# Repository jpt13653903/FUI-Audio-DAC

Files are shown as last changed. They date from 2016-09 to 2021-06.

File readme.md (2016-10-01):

### USB Vendor ID and Product ID

At present, the project uses the Test ID (1209 | 0001) provided by [PID Codes](http://pid.codes/1209/0001).  It is not unique and may therefore not be used outside test environments.

### More Information

For more information, see the [project Wiki](https://sourceforge.net/p/fui-audio-dac/wiki/)

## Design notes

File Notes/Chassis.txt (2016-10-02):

Large Aluminium Enclosure:
http://www.communica.co.za/Catalog/Details/P1733724242

Small Plastic Enclosure:
http://www.mantech.co.za/ProductInfo.aspx?Item=55M0019

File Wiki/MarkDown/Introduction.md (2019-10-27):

[[include repo=source path=Wiki/MarkDown/Header.md]]

[TOC]

# Introduction

## 1. Overview

The FUI Audio DAC is an open-hardware and -firmware project that implements a USB-input fully-digital class-D audio amplifier.  A Microchip PIC-based remote control is also included.

The generic Windows USB&nbsp;audio driver is used to stream 48&nbsp;kSps&nbsp;stereo audio to the amplifier.  The generic Windows&nbsp;HID driver is used to interface a volume control knob and various buttons to the computer.  These buttons are implemented on a remote control, which is implemented by means of an [off-the-shelf 433&nbsp;MHz ASK module](http://www.communica.co.za/Catalog/Details/P1929638763) (FS1000A and C218D001C pair).  Intended functions include *volume up*, *volume down*, *play/pause*, *next track*, *previous track* and *stop* controls.

Volume control is implemented as a combination of bus voltage control and audio stream gain control.

The block diagram below provides a system overview.  The FPGA used for this project is an [Altera Max 10](https://www.altera.com/products/fpga/max-series/max-10/overview.html), which is on a [BeMicro Max 10](https://www.arrow.com/en/products/bemicromax10/arrow-development-tools) development kit.  The microprocessor used for the remote control is a [Microchip PIC16F676](http://www.microchip.com/wwwproducts/en/PIC16F676).

<center markdown>System Block Diagram</center>

## 2. Firmware

All processing is done on FPGA, including the USB-physical, USB-SIE, HID interface, clock-recovery, bus voltage regulation, noise-shaping and PWM output.  An overview of the firmware is provided in the block diagram below.

<center markdown>Firmware Block Diagram</center>

## 3. USB Vendor ID and Product ID

At present, the project uses the Test ID provided by [PID Codes](http://pid.codes/1209/0001).  It is not unique and may therefore not be used outside test environments.

## 4. Development Software

The project is developed using:

- [TinyCAD](https://sourceforge.net/projects/tinycad/)
- [FreePCB](http://freepcb.com/) (or you can use [the fork](https://bitbucket.org/mplough/freepcb/wiki/Home))
- [MPLAB-X](http://www.microchip.com/mplab/mplab-x-ide), which comes with a free version of the [XC&nbsp;compiler](http://www.microchip.com/mplab/compilers)
- [Quartus Prime Lite](https://www.altera.com/products/design-software/fpga-design/quartus-prime/overview.html)
- [InkScape](https://inkscape.org/)

The source is available from the [git repository](https://sourceforge.net/p/fui-audio-dac/source/) and [GitHub](https://github.com/jpt13653903/FUI-Audio-DAC).

[[include repo=source path=Wiki/MarkDown/Footer.md]]

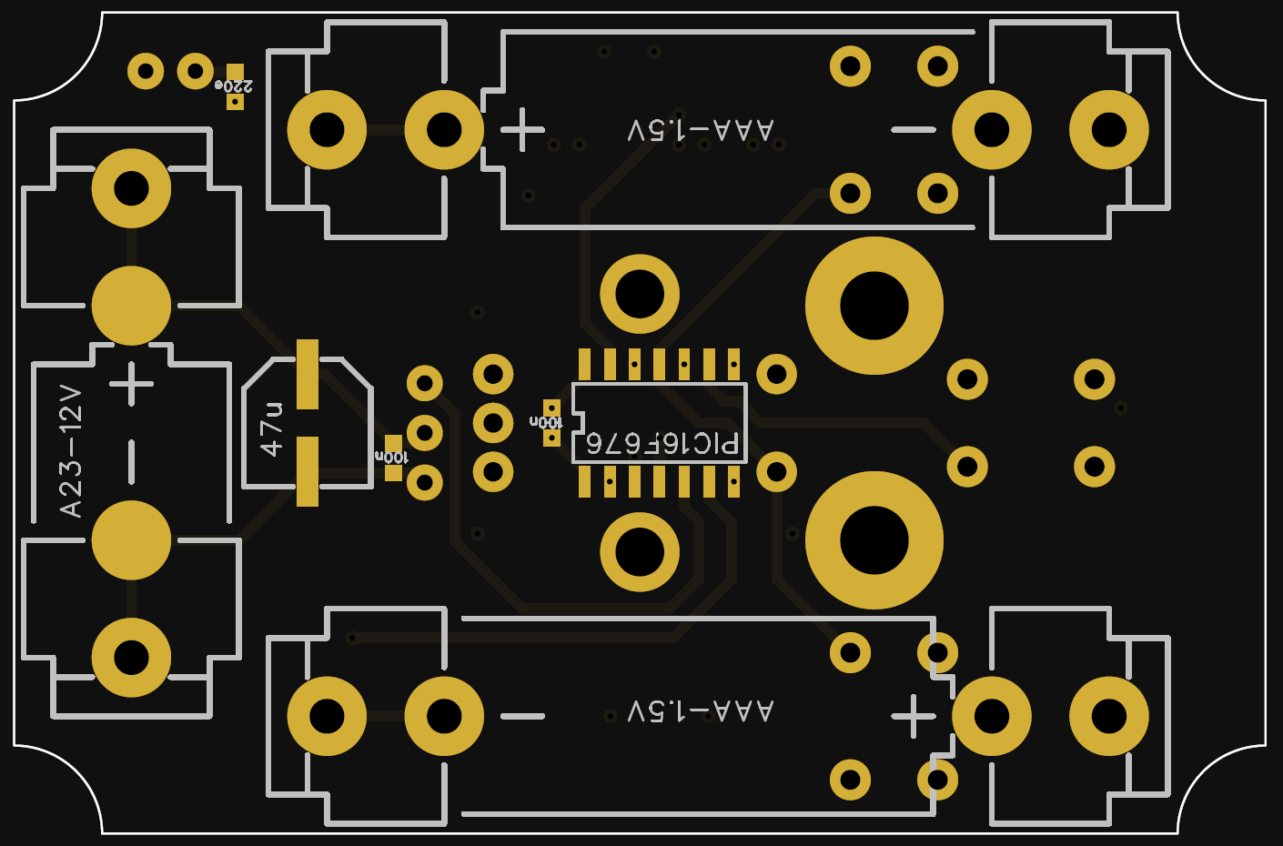
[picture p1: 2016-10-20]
SketchUp/Textures/Remote PCB Bottom.png

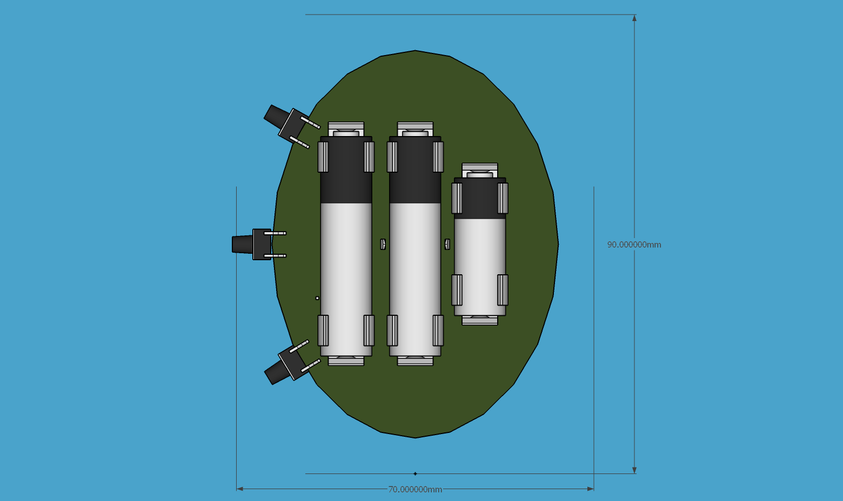
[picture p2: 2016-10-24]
SketchUp/Remote - Side Buttons - Bottom.png

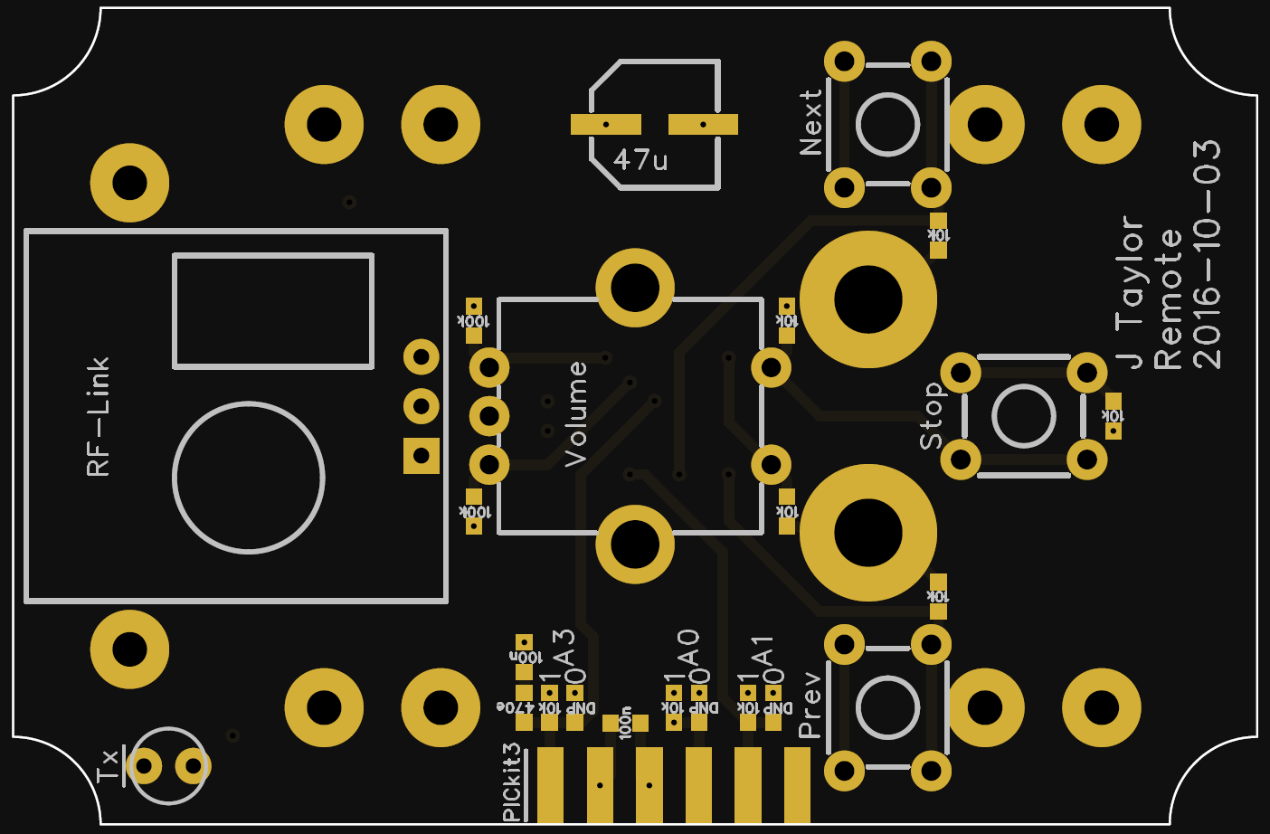
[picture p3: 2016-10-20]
SketchUp/Textures/Remote PCB Top.png

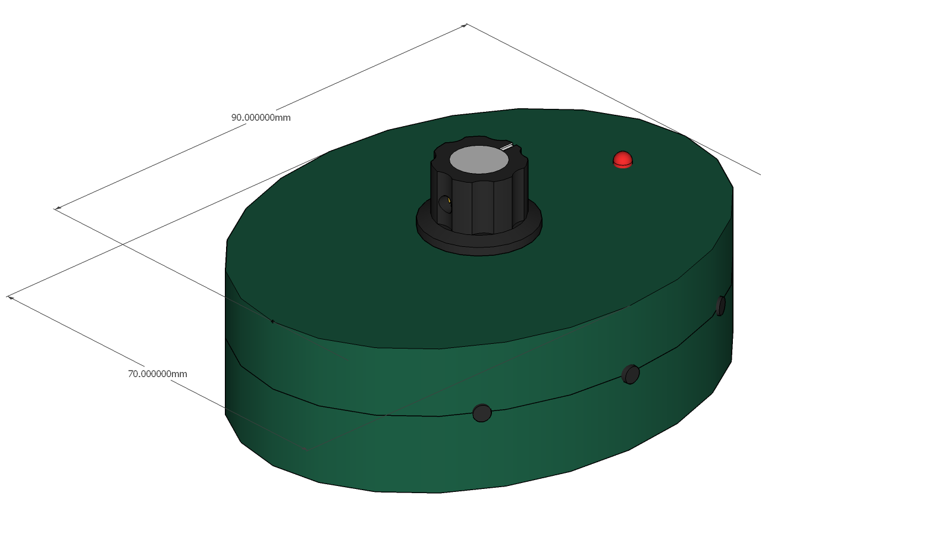
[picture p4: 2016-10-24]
SketchUp/Remote - Side Buttons - Full.png

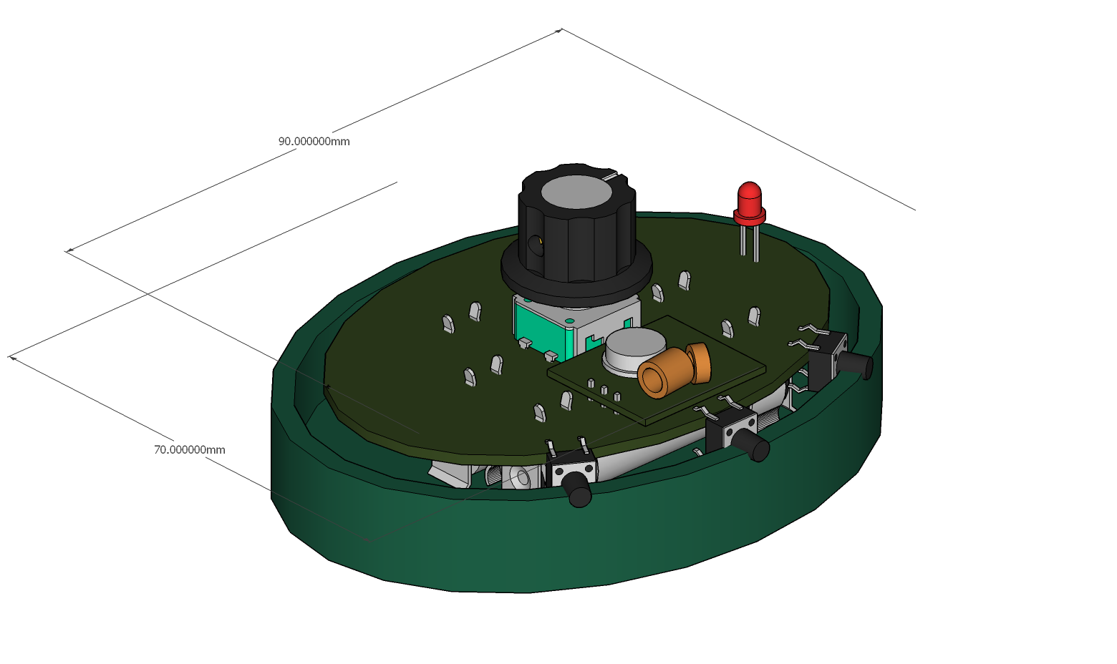
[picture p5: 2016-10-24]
SketchUp/Remote - Side Buttons - Inside.png

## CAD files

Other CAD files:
Quartus/USB Amplifier/USB_Amplifier.stp
SketchUp/Amplifier.skp
SketchUp/Remote - Side Buttons.skp
SketchUp/Remote.skp

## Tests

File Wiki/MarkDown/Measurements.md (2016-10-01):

[[include repo=source path=Wiki/MarkDown/Header.md]]

[TOC]

# Measurements

## 1. Remote
### 1.1 Power Requirements

These measurements were performed without the RF-link, at `Vcc` = 5&nbsp;V:

- The stand-by current is 40&nbsp;&micro;A
- While sending data, the supply current is 6.35&nbsp;mA.

These measurements were performed with the RF-link, at `Vcc` = 5&nbsp;V:

- The stand-by current is 40&nbsp;&micro;A
- While sending data, the supply current is 11.7&nbsp;mA.

Assuming that the battery capacity is 1&nbsp;Ah, as is typical for alkaline AAA batteries, this would imply a stand-by life-time of about 2&nbsp;years.

[[include repo=source path=Wiki/MarkDown/Footer.md]]

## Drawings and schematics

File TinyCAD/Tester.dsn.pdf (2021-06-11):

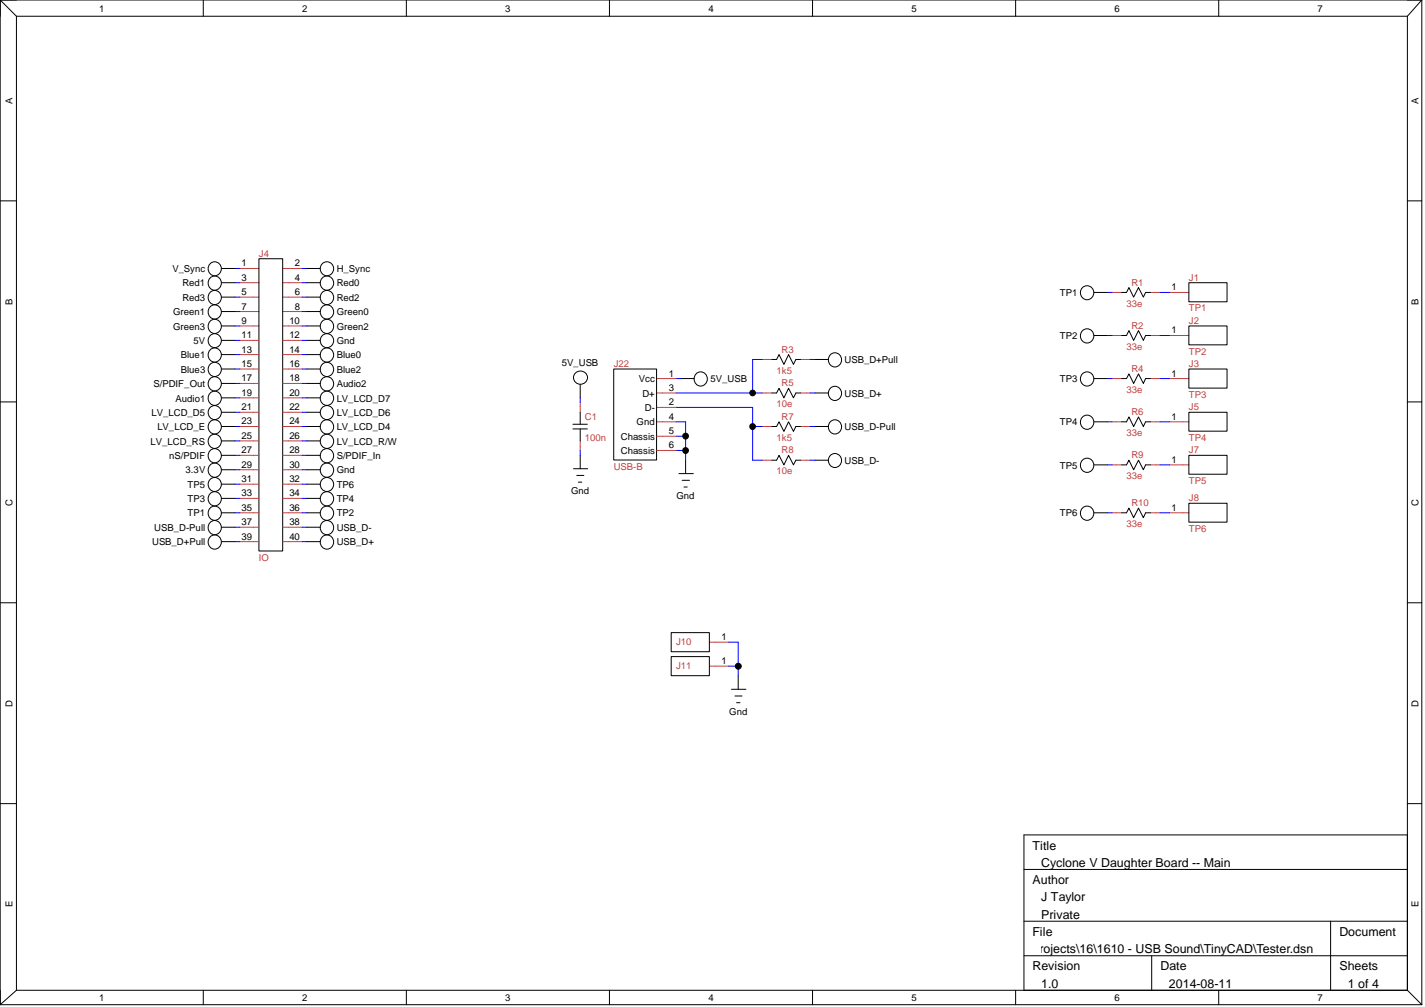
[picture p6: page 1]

Title
Cyclone V Daughter Board -- Main
Author
J Taylor
Private
File
C:\JPT\Projects\16\1610 - USB Sound\TinyCAD\Tester.dsn
Revision

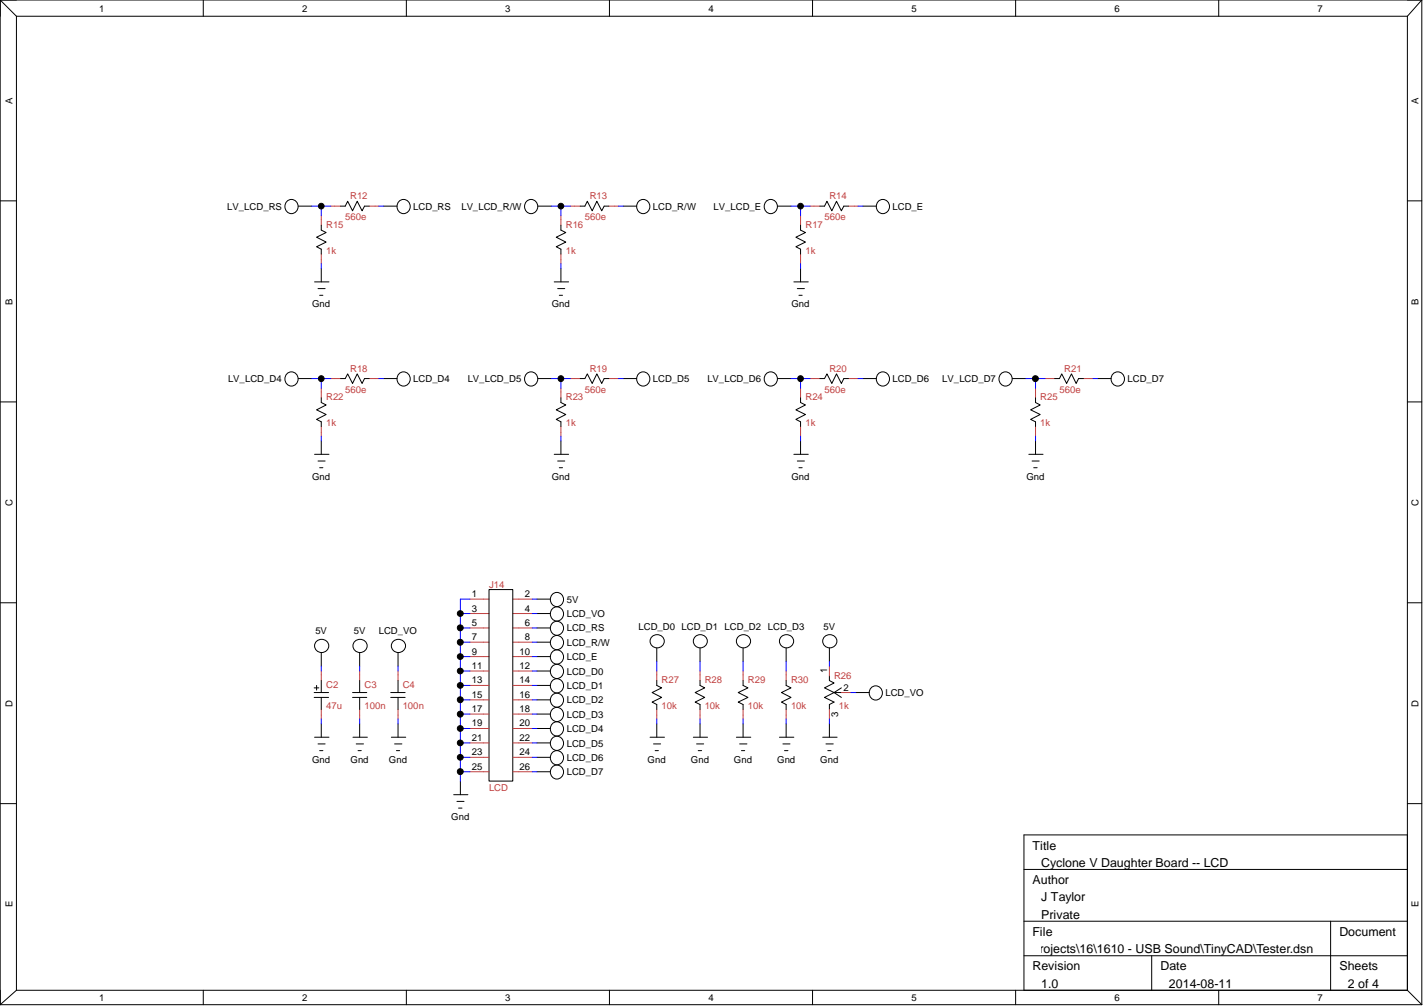
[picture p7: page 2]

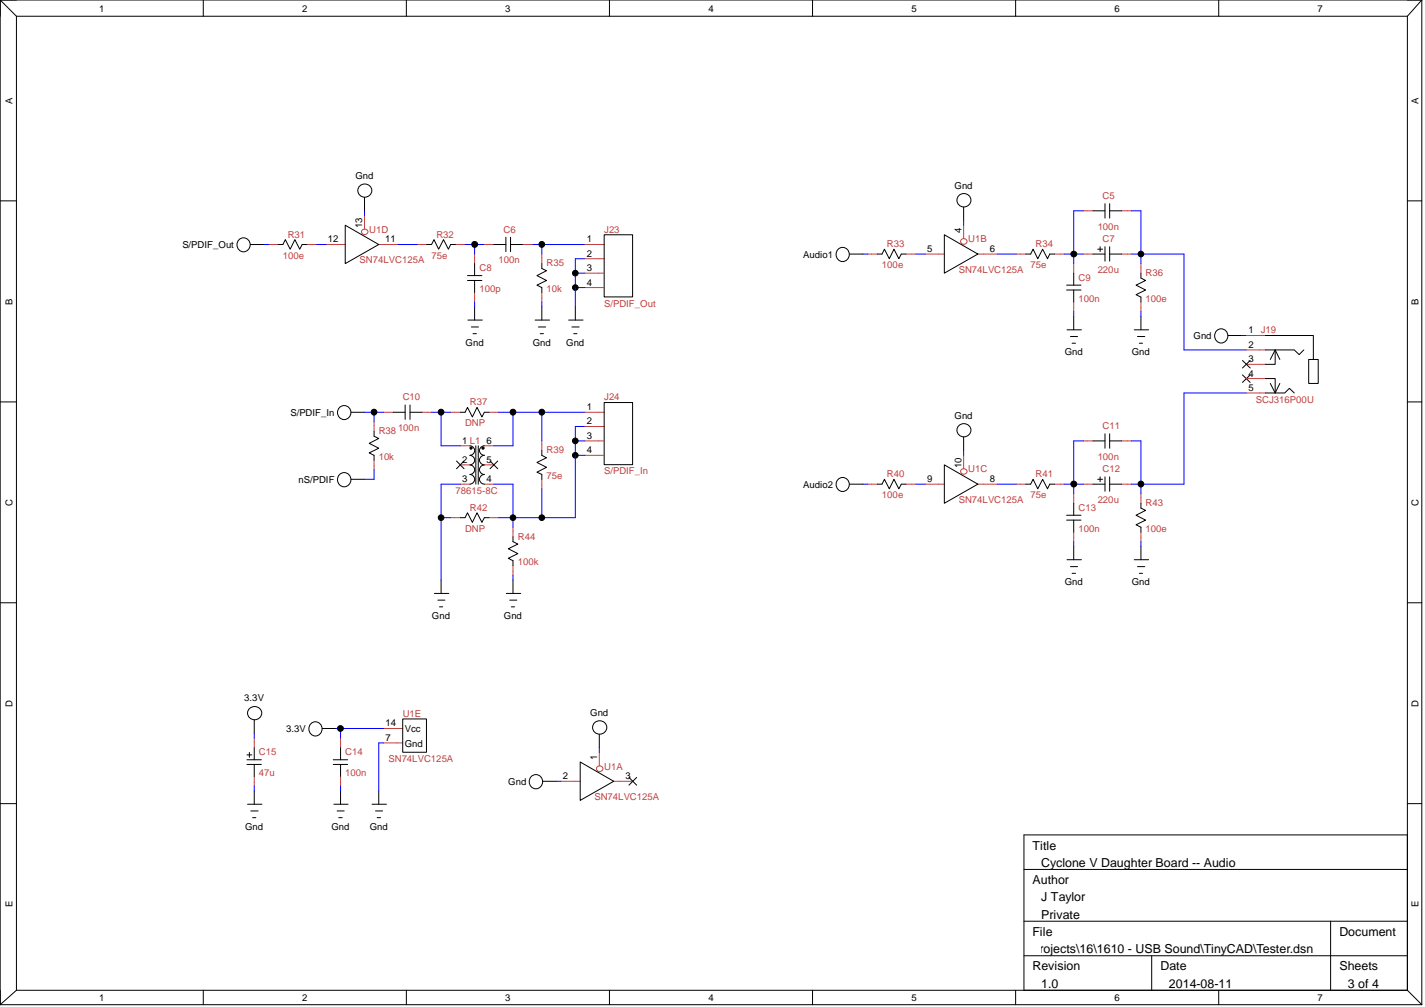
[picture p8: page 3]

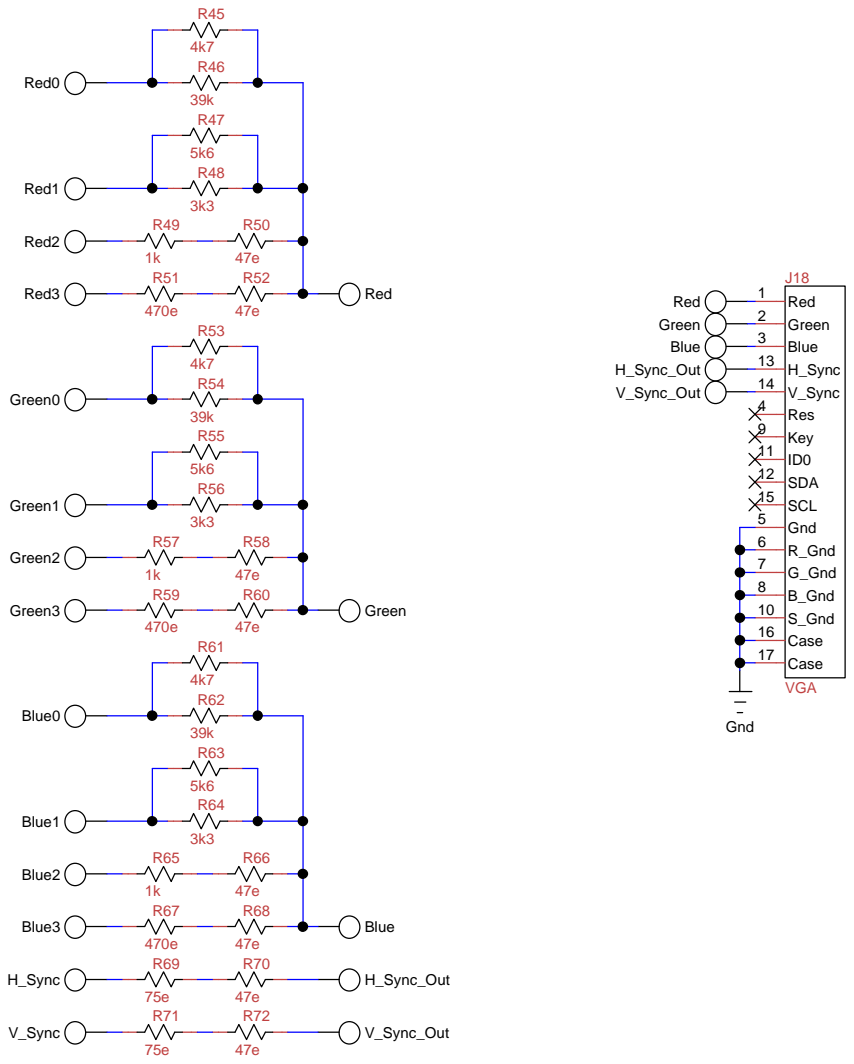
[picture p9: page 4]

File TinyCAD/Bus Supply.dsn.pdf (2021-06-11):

## Vdd is typically 3.3V, provided

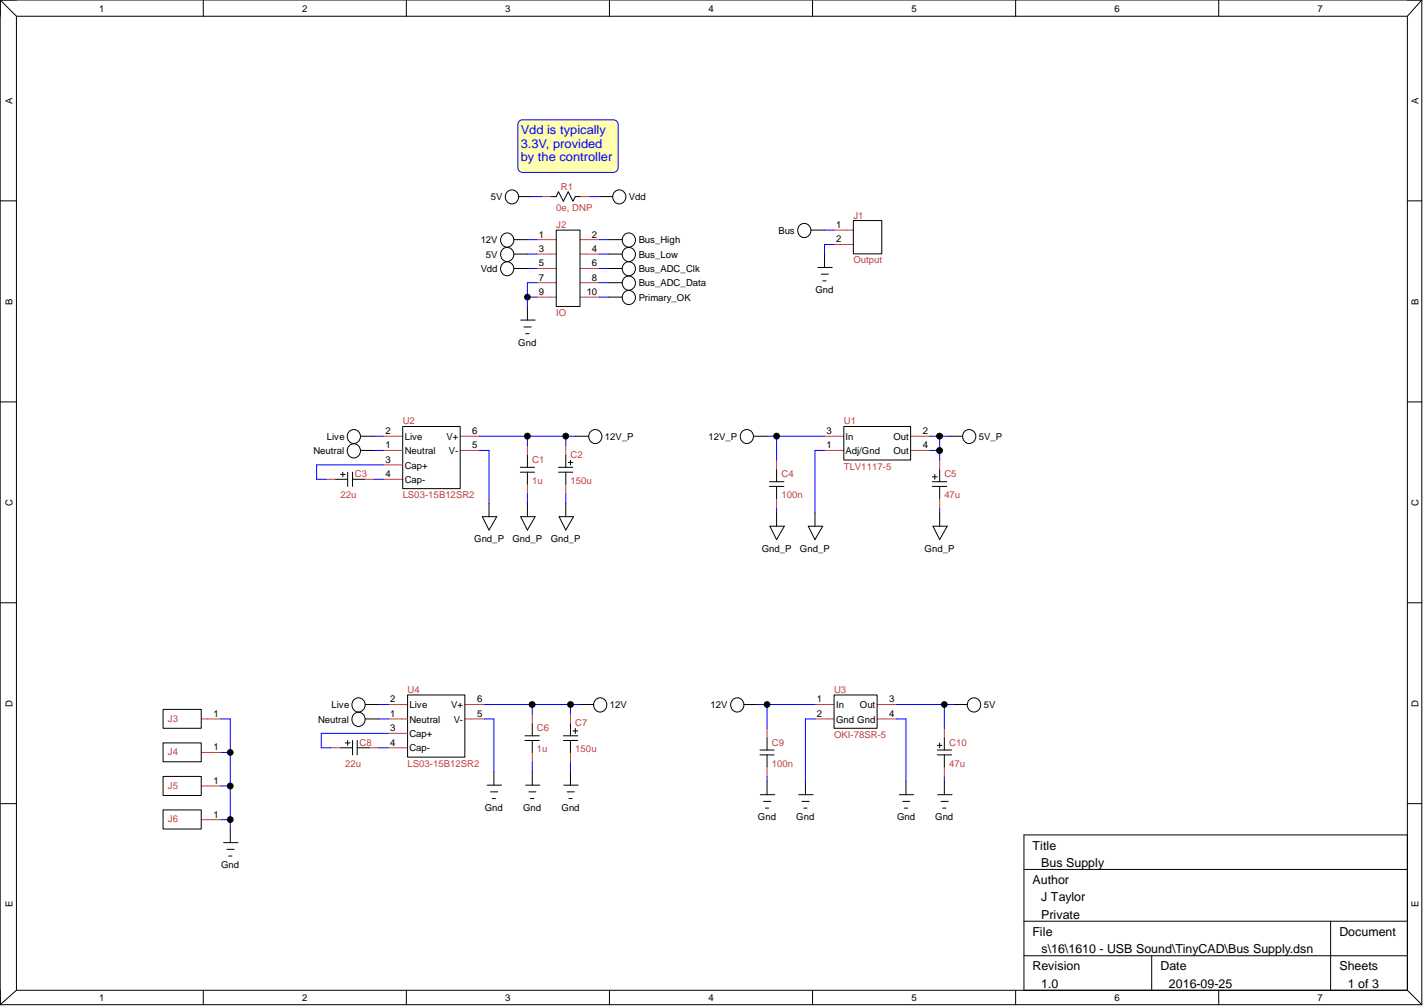
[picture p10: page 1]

C:\JPT\Projects\16\1610 - USB Sound\TinyCAD\Bus Supply.dsn

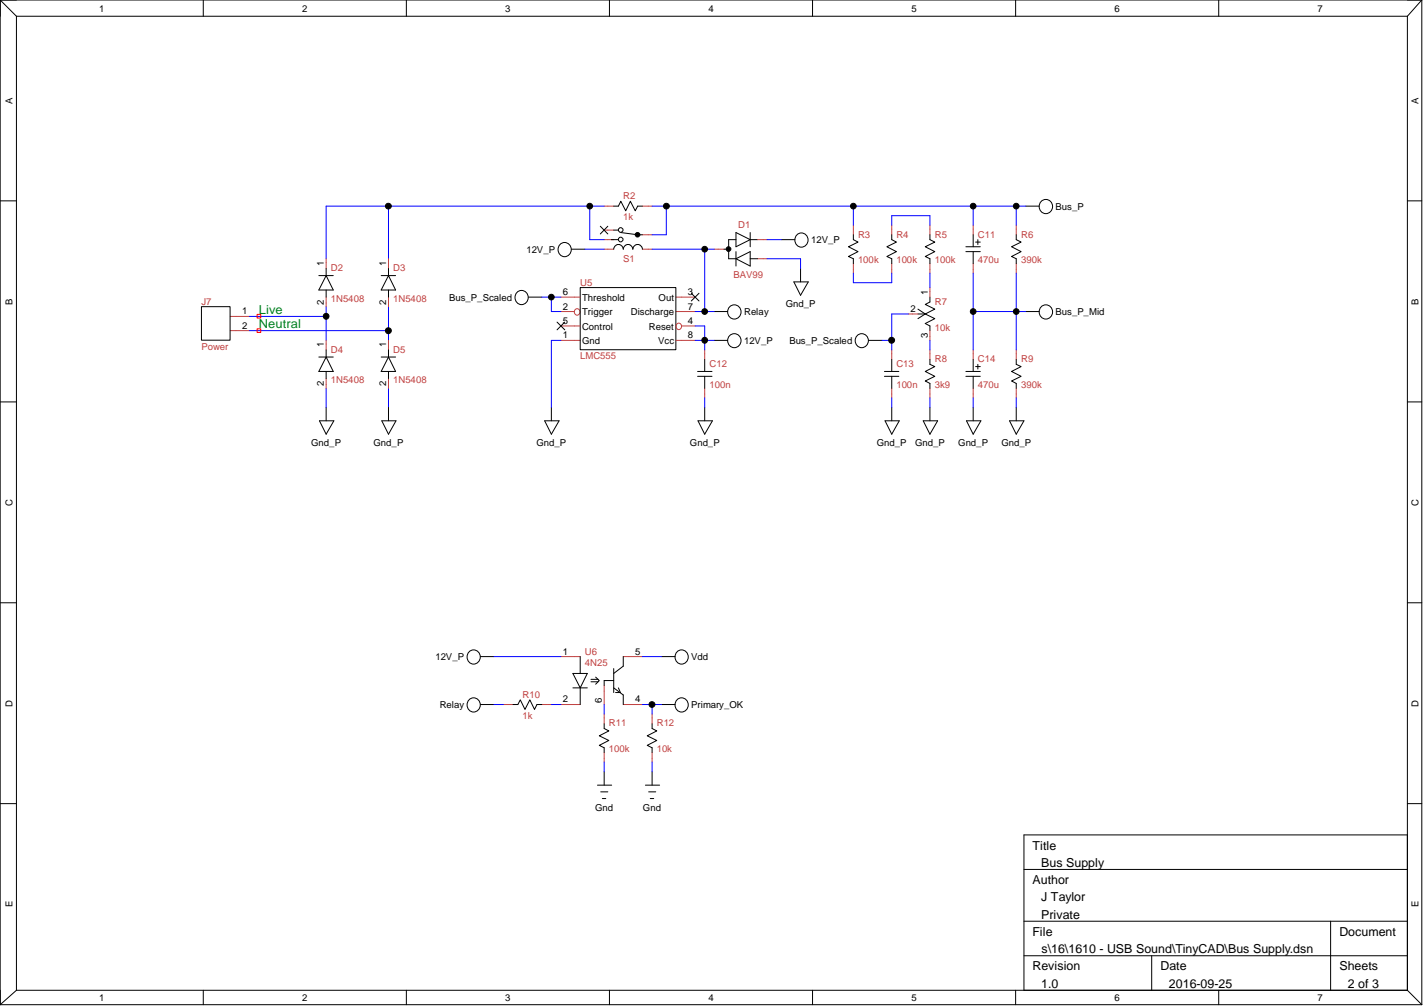
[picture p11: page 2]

## MAX10 configuration pull-up is

7 kΩ, minimum.

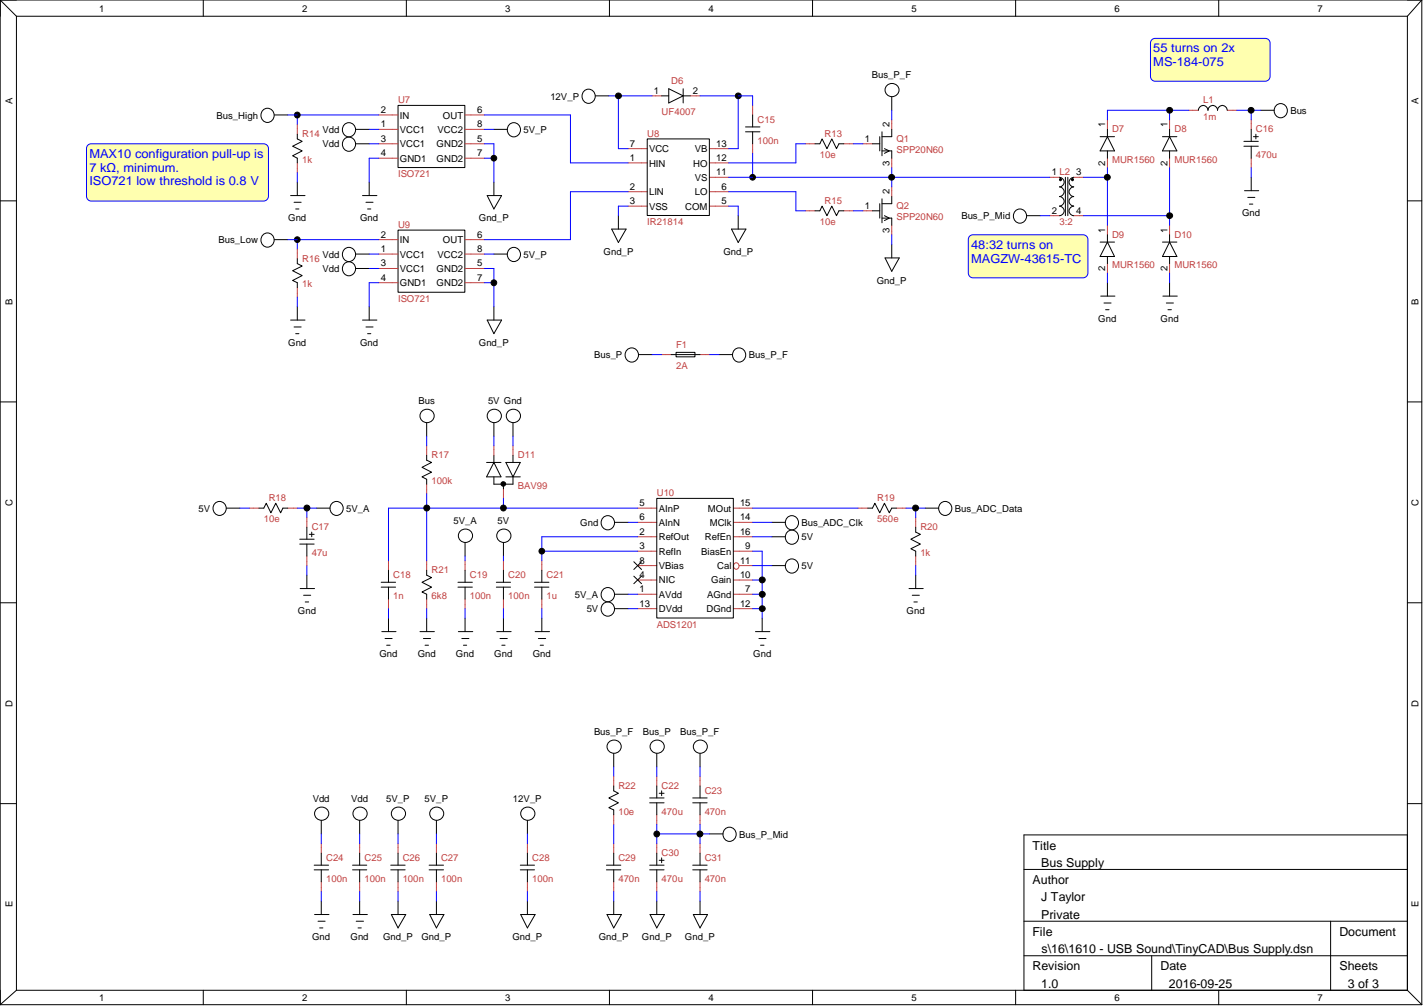
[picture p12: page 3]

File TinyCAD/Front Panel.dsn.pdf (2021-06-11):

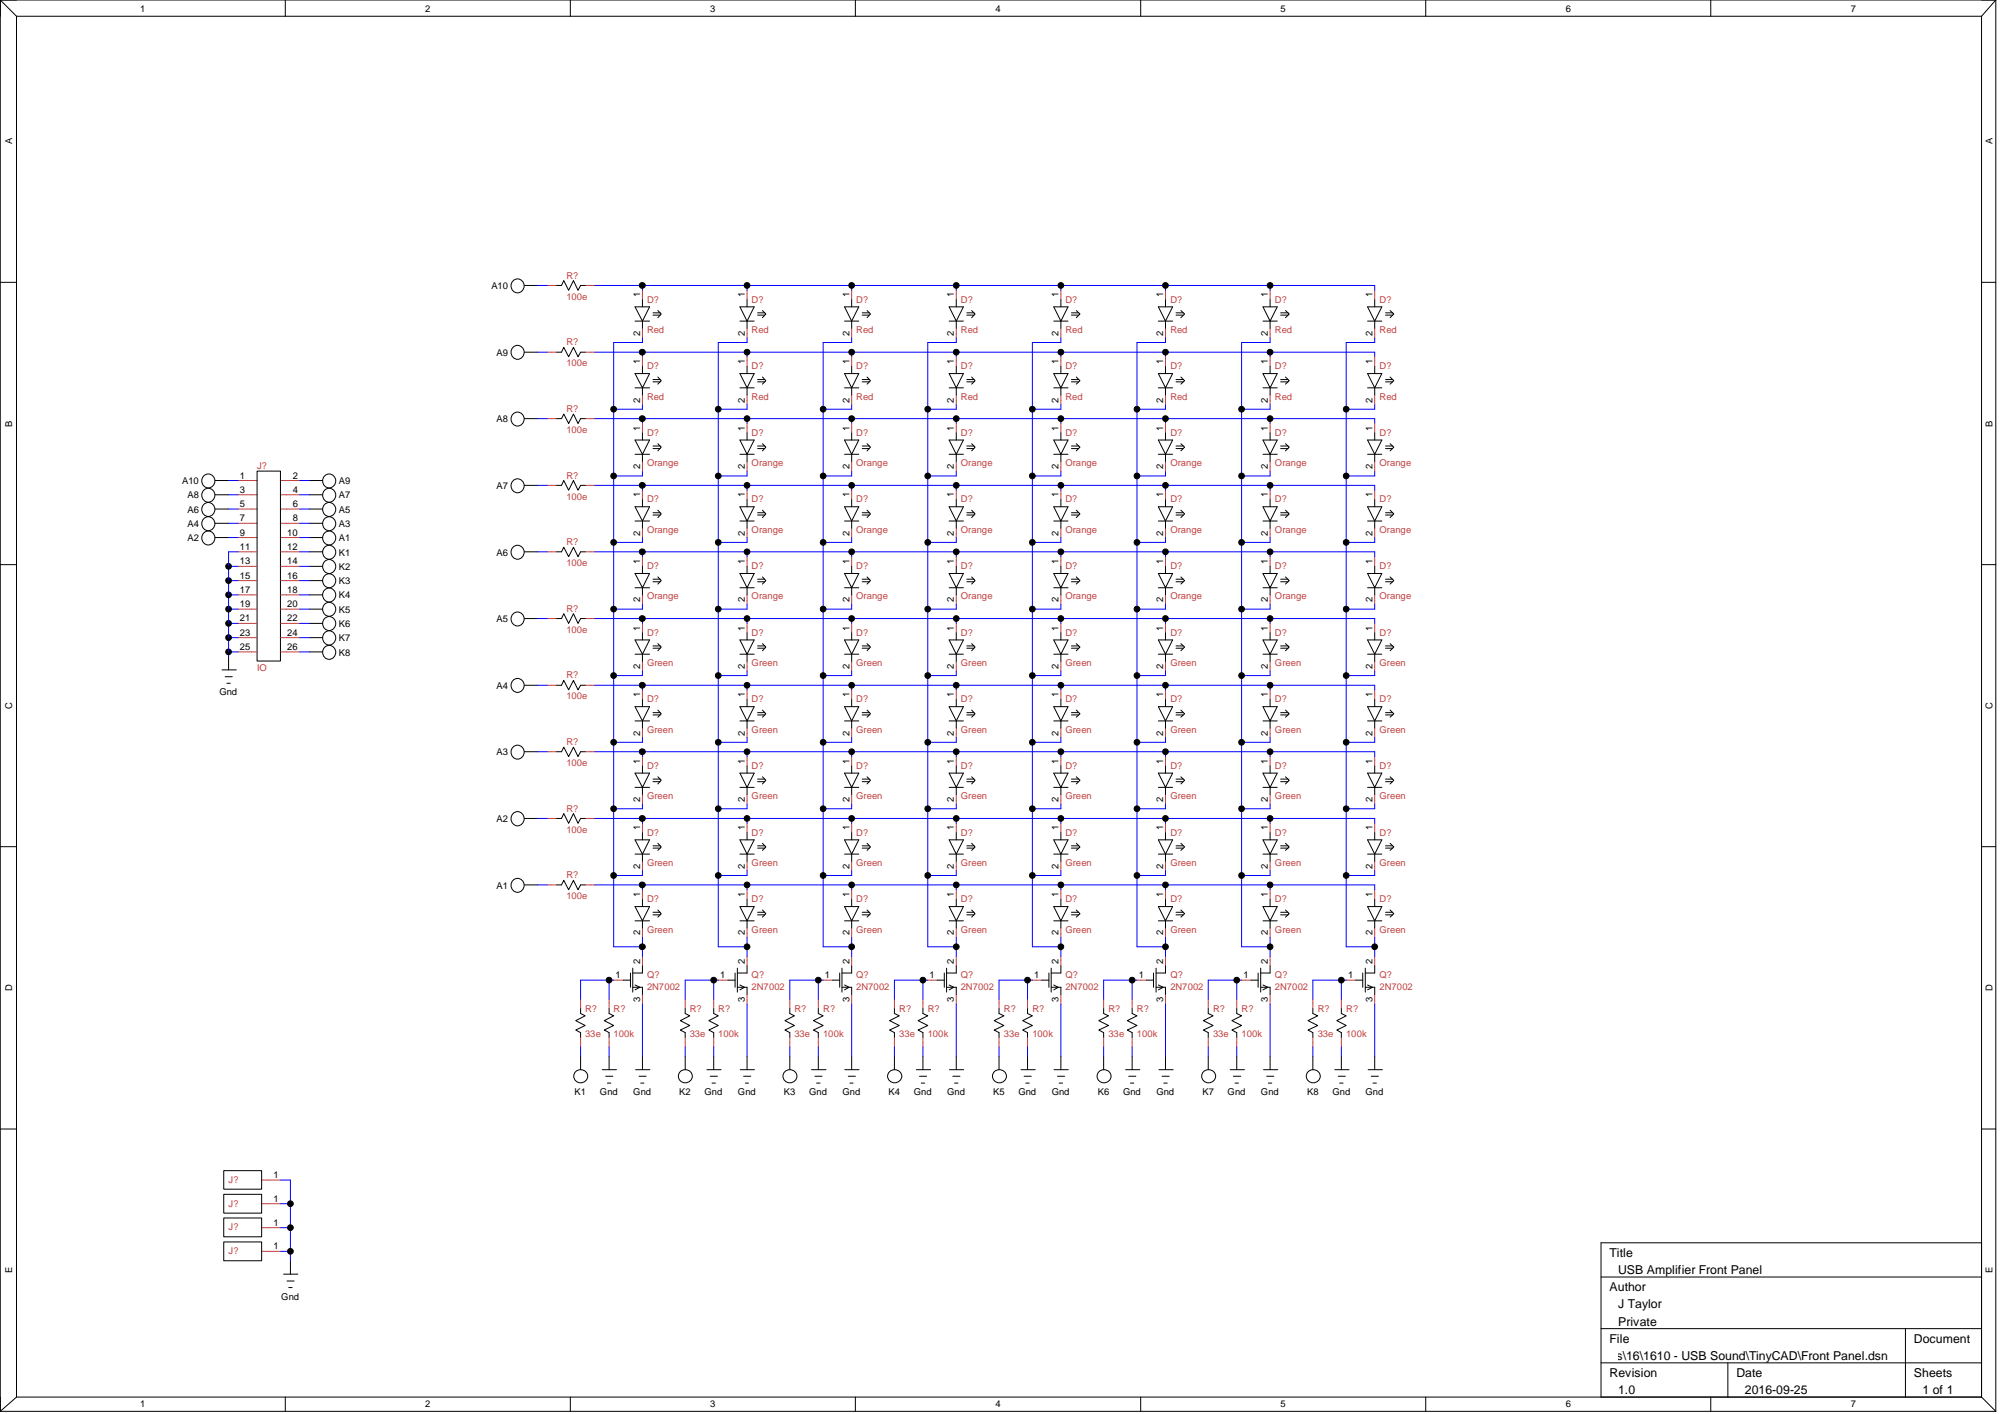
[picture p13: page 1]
Gnd; Orange; Green; Red; Revision; Document; Date; Sheets

Title
USB Amplifier Front Panel
Author
J Taylor
Private
File

C:\JPT\Projects\16\1610 - USB Sound\TinyCAD\Front Panel.dsn

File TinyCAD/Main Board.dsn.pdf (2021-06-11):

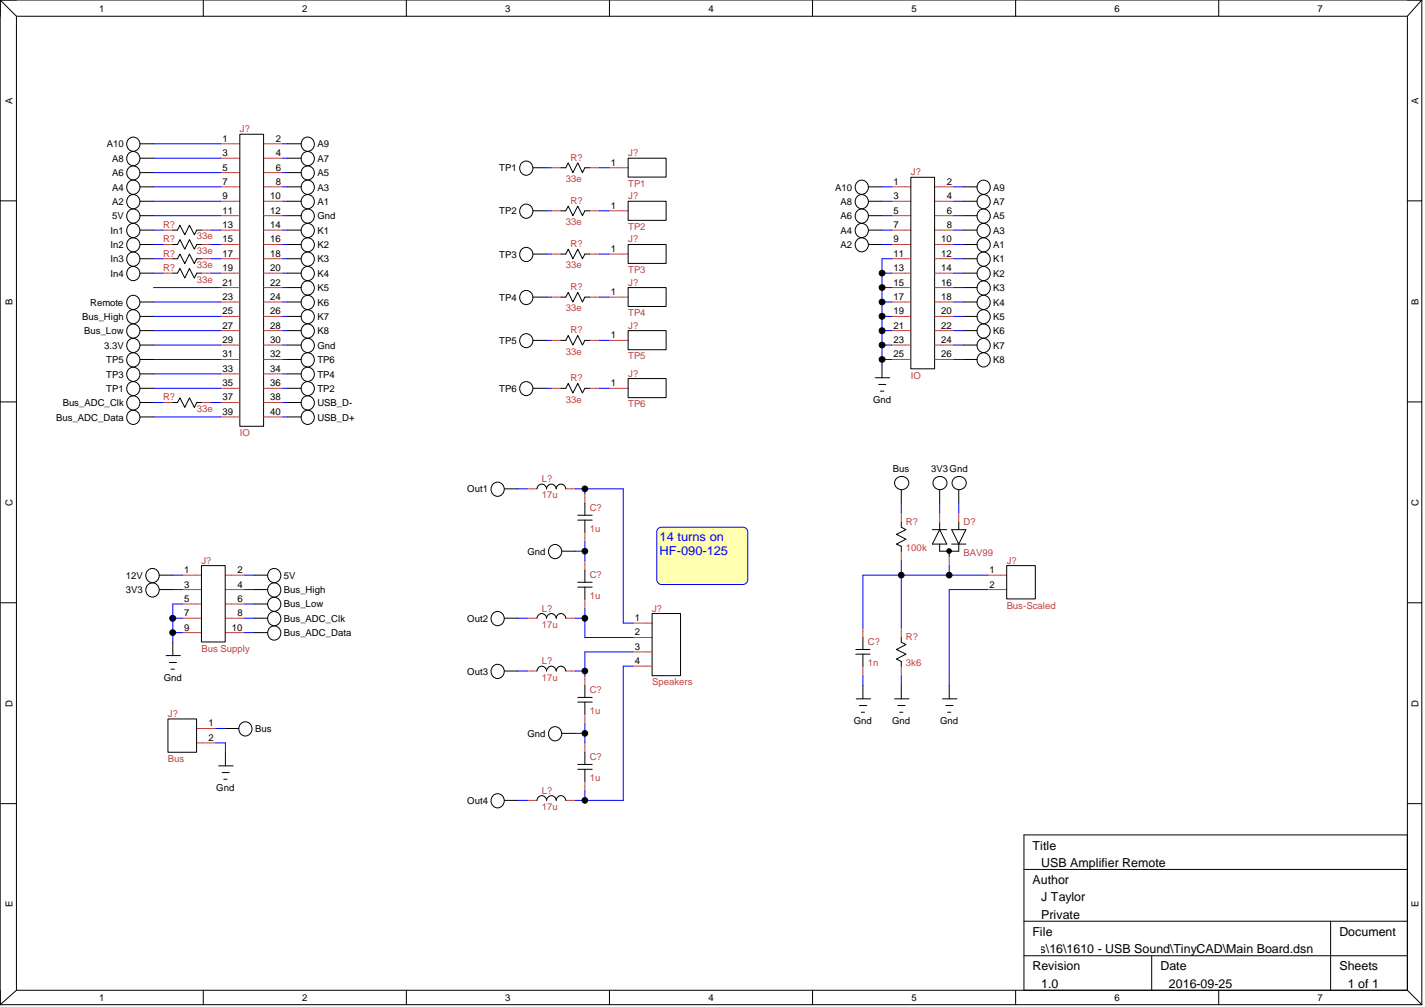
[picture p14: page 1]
Gnd; USB_D+; USB_D-; Bus_ADC_Clk Bus_ADC_Data; Bus_Low; Bus_High; Remote; L? 17u Out3; L? 17u Out4; L? 17u Out1; L? 17u Out2; Speakers; 14 turns on HF-090-125; Bus Supply; Bus; Bus-Scaled; BAV99; 3V3 Gnd; Title; Author; File; Revision; Document; Date; Sheets; USB Amplifier Remote; J Taylor Private

C:\JPT\Projects\16\1610 - USB Sound\TinyCAD\Main Board.dsn

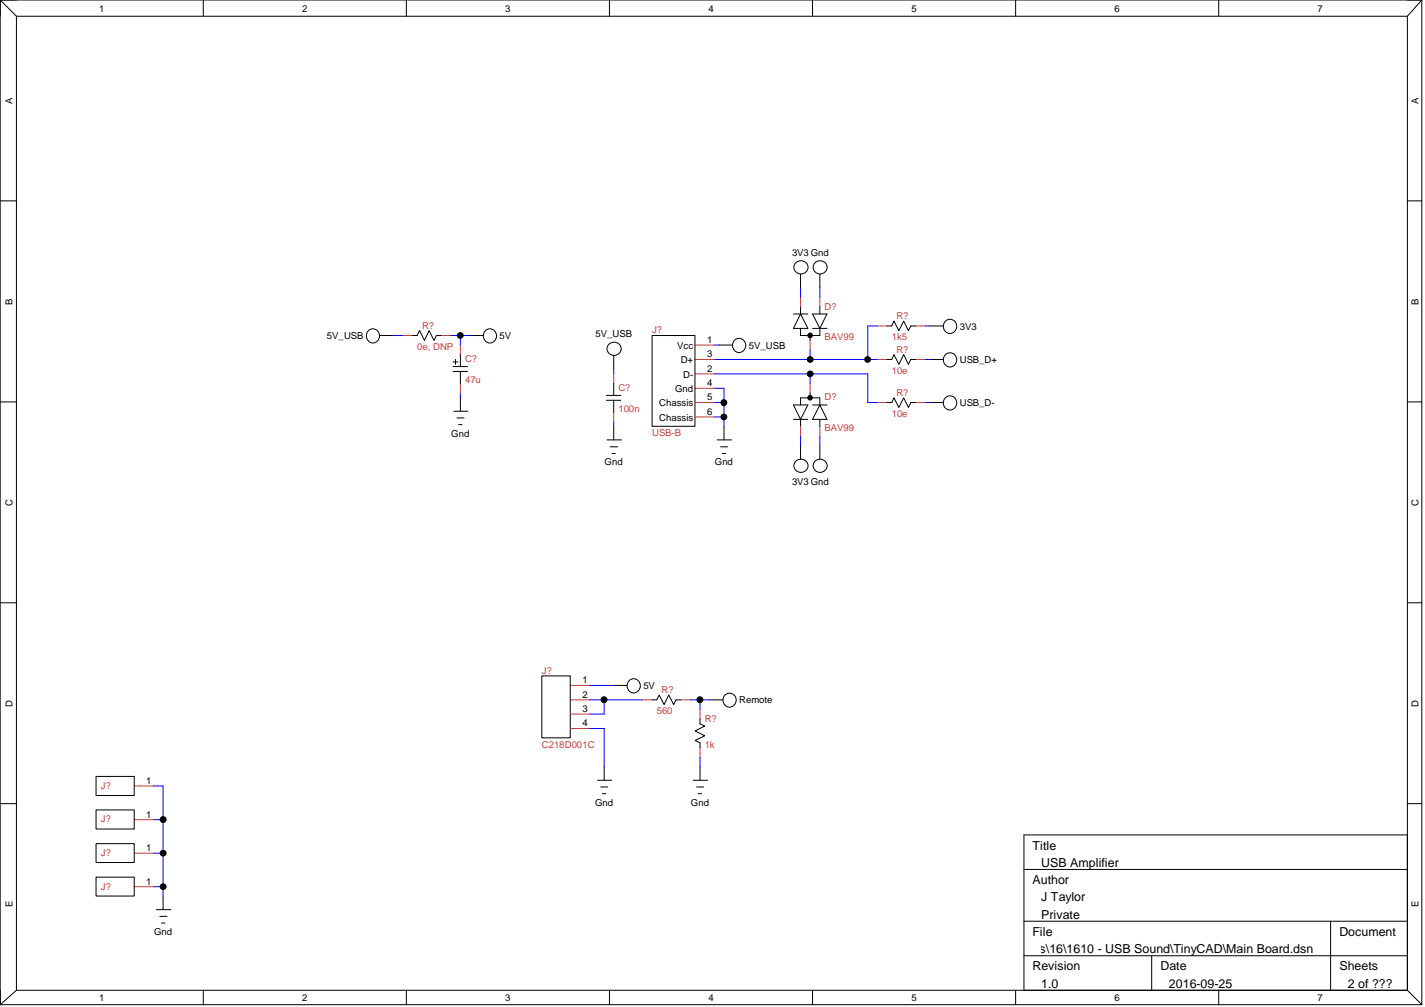
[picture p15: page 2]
Gnd; 5V_USB; USB_D+; USB_D-; Vcc; 3 Gnd; 2 Chassis; Chassis; USB-B; BAV99; 3V3 Gnd; 0e, DNP; Remote; Title; Author; USB Amplifier; J Taylor Private

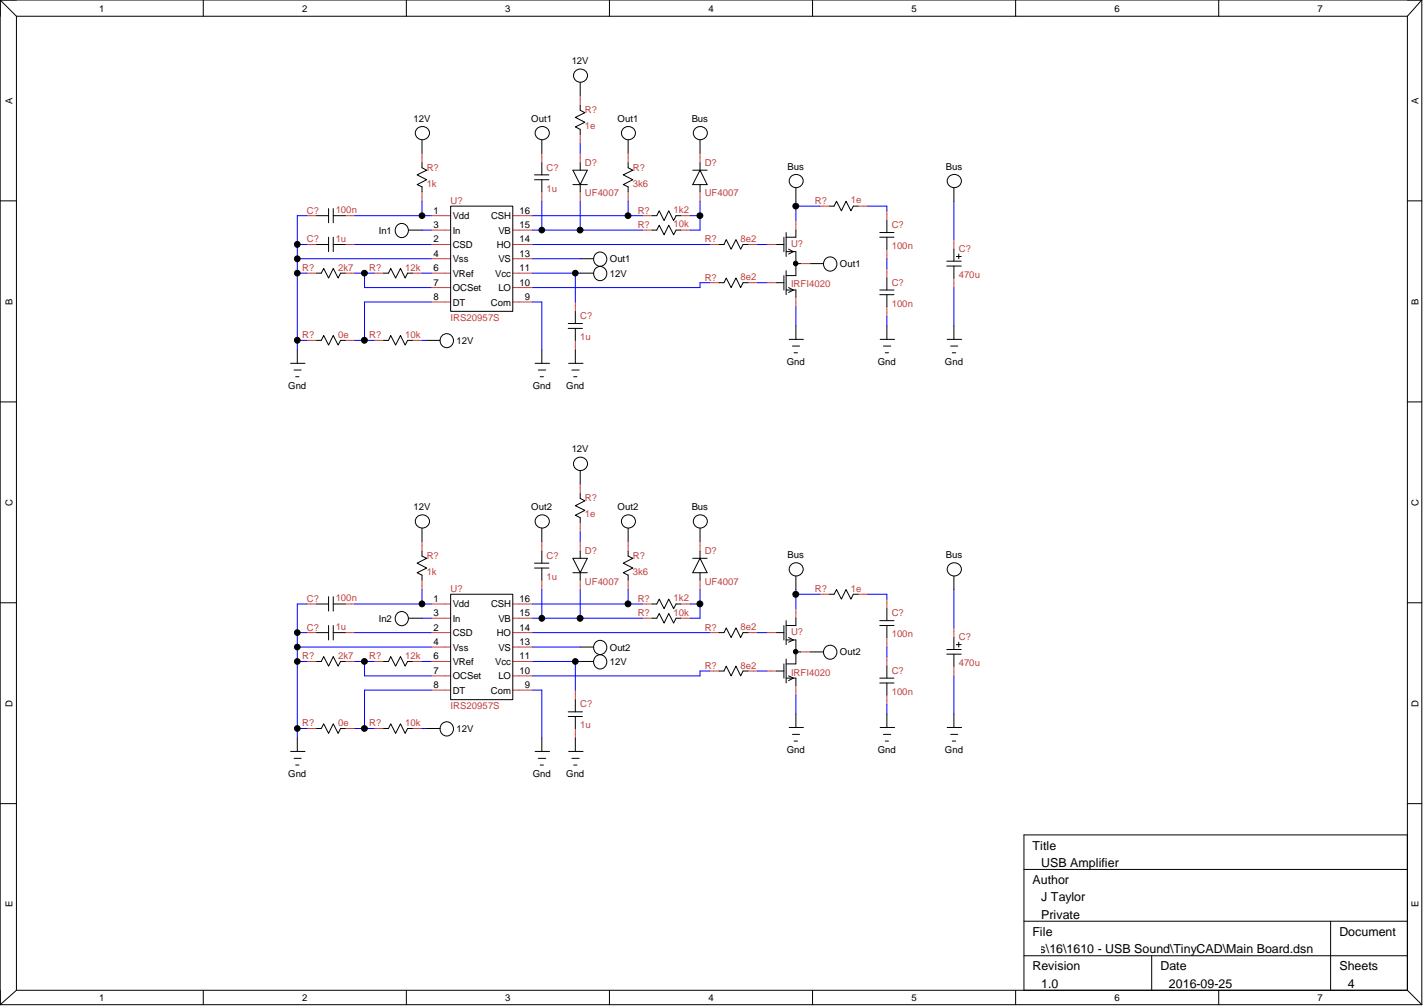
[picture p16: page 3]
Bus; Gnd; Out1; IRFI4020; Vdd 1; CSD 2; Vss 4 VRef 6 OCSet 7; Com; Vcc 11; CSH 16; IRS20957S; Out2; Title; Author; USB Amplifier; J Taylor Private

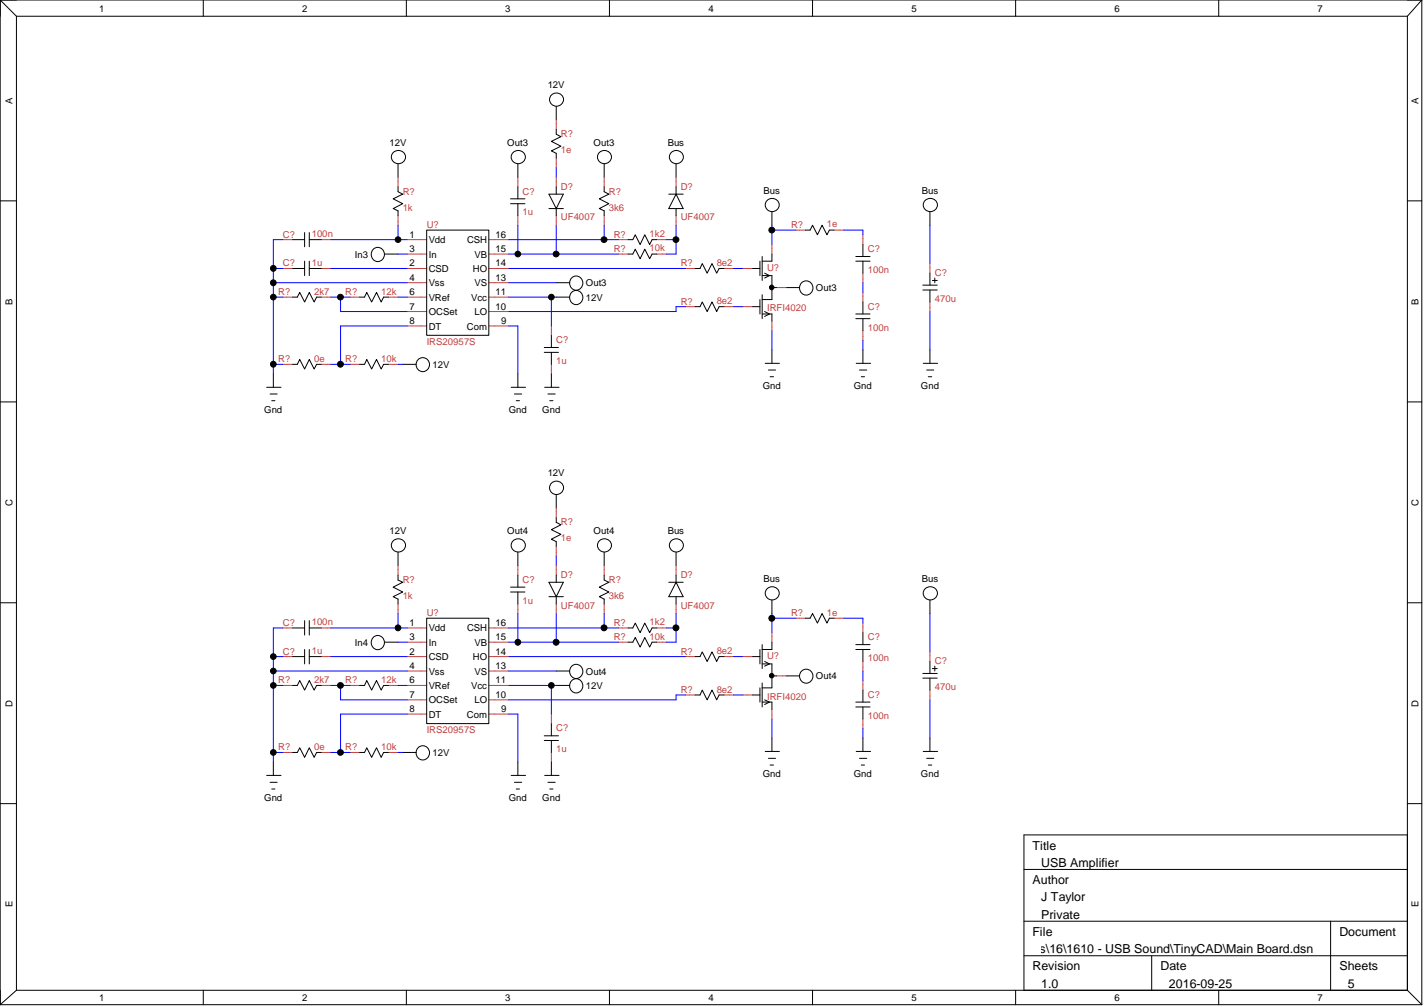
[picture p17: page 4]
Bus; Gnd; Out3; IRFI4020; Vdd 1; CSD 2; Vss 4 VRef 6 OCSet 7; Com; Vcc 11; CSH 16; IRS20957S; Out4; Title; Author; USB Amplifier; J Taylor Private

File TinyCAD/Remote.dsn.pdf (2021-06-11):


Note: On the RF Tx,
mod the signal input
resistor to 5k6

C:\JPT\Projects\16\1610 - USB Sound\TinyCAD\Remote.dsn

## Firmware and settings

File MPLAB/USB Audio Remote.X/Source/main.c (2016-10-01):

//==============================================================================
// Copyright (C) John-Philip Taylor
// jpt13653903@gmail.com
//
// This file is part of FUI Audio DAC
//
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
#include "config.h"
#include "global.h"
//------------------------------------------------------------------------------

bool Active      = false;
byte ActiveCount = 0;
byte Knob        = 0;
//------------------------------------------------------------------------------

void MakeActive(){
 Active      = true;
 ActiveCount = 0;

 Interrupt        = 1;
 TRISC            = 0xCF;
 TRISAbits.TRISA2 = 0;

 INTCONbits.INTE = 0;
 INTCONbits.T0IE = 1;
}
//------------------------------------------------------------------------------

void OnKnobChange(){
 static byte Prev = 0;
 
 byte Next = (Knob2 << 1) | Knob1;

 switch((Prev << 4) | Next){
  case 0x01:
  case 0x13:
  case 0x32:
  case 0x20:
   Knob++;
   break;

  case 0x02:
  case 0x10:
  case 0x31:
  case 0x23:
   Knob--;
   break;

  default:
   break;
 }

 Prev = Next;
}
//------------------------------------------------------------------------------

byte Parity(word Data){
 byte Result;

 Result = (Data   & 0xFF) ^ (Data   >> 8);
 Result = (Result & 0x0F) ^ (Result >> 4);
 Result = (Result & 0x03) ^ (Result >> 2);
 Result = (Result & 0x01) ^ (Result >> 1);
 
 // Has to be odd parity to ensure that the final edge is falling
 return (~Result) & 1;
}
//------------------------------------------------------------------------------

void OnTimer(){
 typedef enum STATE_TAG{
  Idle,
  SendEdge,
  SendData
 } STATE;
 
 static STATE State = Idle;
 static byte  Count = 0;
 static word  Data;

 switch(State){
  case Idle:
   Count++;
   if(Count == 3){
    Data = Buttons;
    Data = (Data << 8) | Knob;
    Data = (Data << 4) | Parity(Data);

    Count = 0;
    State = SendEdge;
   }
   break;

  case SendEdge:
   Tx = !Tx;

   if(Count == 16){
    ActiveCount++;
    if(ActiveCount > 25) Active = false;

    Count = 0;
    State = Idle;

   }else{
    State = SendData;
   }
   break;

  case SendData:
   if(Data & 0x8000) Tx = !Tx;
   Data = Data << 1;

   Count++;
   State = SendEdge;

   break;

  default:
   break;
 }
}
//------------------------------------------------------------------------------

interrupt void OnInterrupt(){
 // Interrupt-on-change, port A
 if(INTCONbits.RAIF){
  MakeActive    ();
  INTCONbits.RAIF = 0;
 }

 // Interrupt on falling edge of INT pin
 if(INTCONbits.INTF){
  MakeActive();
  INTCONbits.INTF = 0;
 }

 // Interrupt on Timer 0 overflow
 if(INTCONbits.T0IF){
  if(Buttons) ActiveCount = 0;

  OnKnobChange(); // Uses slow-sampling to de-bounce: sample every 500 μs

  OnTimer();

  INTCONbits.T0IF = 0;
 }

 INTCONbits.T0IE = Active;
 LED             = Active;
}
//------------------------------------------------------------------------------

void main(){
 OPTION_REGbits.nRAPU  = 1; // Disable weak pull-ups
 OPTION_REGbits.INTEDG = 0; // Interrupt on falling edge of INT pin
 OPTION_REGbits.T0CS   = 0; // Timer 0 uses internal clock
 OPTION_REGbits.PSA    = 0; // Prescaler assigned to Timer 0
 OPTION_REGbits.PS     = 0; // Timer 0 rate => 2 μs clock / 512 μs interrupt

 CMCONbits .CM   = 7; // Switch off the comparators
 ADCON0bits.ADON = 0; // Switch off the ADC

 ANSEL = 0; // Disable analogue functionality
 WPUA  = 0; // Disable weak pull-up on port A

 IOCA            = 0x30; // Interrupt-on-change on A4 and A5
 INTCONbits.RAIE = 1;    // Enable port A interrupt-on-change

 while(1){
  if(!Active){
   INTCONbits.GIE = 0;
    PORTC = 0;
    TRISA = 0xFF;
    TRISC = 0xC0;
    INTCONbits.INTF = 0;
    INTCONbits.INTE = 1;
   INTCONbits.GIE = 1;
   SLEEP();
  }
 }
}
//------------------------------------------------------------------------------

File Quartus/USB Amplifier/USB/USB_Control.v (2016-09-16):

//==============================================================================
// Copyright (C) John-Philip Taylor
// jpt13653903@gmail.com
//
// This file is part of a library
//
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
// For all arrays, 0 => Left, 1 => Right
//------------------------------------------------------------------------------

module USB_Control(
 input Clk,
 input Reset,
 input Error,

 output reg [6:0]Address,
 output reg      Stall,

 input           OUT_Setup,
 input           OUT_SoP,
 input           OUT_EoP,
 output          OUT_WaitRequest,
 input      [7:0]OUT_Data,
 input           OUT_Sequence,
 input           OUT_Valid,
 output          OUT_Isochronous,
 
 output reg      IN_Sequence,
 output reg [7:0]IN_Data,
 output reg      IN_Ready,
 output          IN_ZeroLength,
 input           IN_WaitRequest,
 input           IN_Ack,
 output          IN_Isochronous,

 output reg      Active,
 output reg      Mute,
 output reg [7:0]Volume[1:0]
);
//------------------------------------------------------------------------------

`include "USB_Constants.vh"
//------------------------------------------------------------------------------

assign OUT_WaitRequest = 1'b0;
assign OUT_Isochronous = 1'b0;

assign IN_Isochronous  = 1'b0;
//------------------------------------------------------------------------------

reg  [9:0]Descriptor_Address;
wire      Descriptor_ClockEnable = 1'b1;
reg  [7:0]Descriptor_Data;

USB_Descriptors USB_Descriptors_Inst(
 .address(Descriptor_Address),
 .clken  (Descriptor_ClockEnable),
 .clock  (Clk),
 .q      (Descriptor_Data)
);
//------------------------------------------------------------------------------

reg       Direction;
reg [ 1:0]Type;
reg [ 4:0]Recipient;
reg [ 7:0]Request;
reg [15:0]Value;
reg [15:0]Index;
reg [15:0]Length;
reg [ 6:0]ByteCount;
reg [15:0]DataSize;

reg [15:0]Temp;

assign IN_ZeroLength = ~|DataSize;
//------------------------------------------------------------------------------

reg   [5:0]State;
localparam Idle             = 6'd_0;
localparam GetRequest       = 6'd_1;
localparam GetValueLow      = 6'd_2;
localparam GetValueHigh     = 6'd_3;
localparam GetIndexLow      = 6'd_4;
localparam GetIndexHigh     = 6'd_5;
localparam GetLengthLow     = 6'd_6;
localparam GetLengthHigh    = 6'd_7;
localparam GetEoP           = 6'd_8;
localparam GetDescriptor    = 6'd_9;
localparam SetAddress       = 6'd10;
localparam SetConfiguration = 6'd11;
localparam SetInterface     = 6'd12;

localparam SetControl  = 6'd13;
localparam GetControl  = 6'd14;
localparam SendControl = 6'd15;

localparam SendData = 6'd62;
localparam GetAck   = 6'd63;
//------------------------------------------------------------------------------

wire [7:0]Descriptor_Type  = Value[15:8];
wire [7:0]Descriptor_Index = Value[ 7:0];
wire [7:0]ControlSelect    = Value[15:8];
wire [7:0]ChannelSelect    = Value[ 7:0];
wire [7:0]UnitID           = Index[15:8];
wire [7:0]Interface        = Index[ 7:0];
//------------------------------------------------------------------------------

reg tReset;
always @(posedge Clk) begin
 tReset <= Reset;
//------------------------------------------------------------------------------

 if(tReset) begin
  Active    <= 0; // Idle (i.e. no sound)
  Mute      <= 0; // False
  Volume[0] <= 8'hBD; // 75%
  Volume[1] <= 8'hBD;

  Address <= 0;
  Stall   <= 0;

  IN_Sequence <= 0;
  IN_Ready    <= 0;

  State <= Idle;

  ByteCount <= 0;
//------------------------------------------------------------------------------

 end else if(OUT_Valid & OUT_SoP & OUT_Setup) begin
   IN_Ready    <= 1'b0;
   Stall       <= 0;
   IN_Sequence <= 1'b1;
   {Direction, Type, Recipient} <= OUT_Data;
   State <= GetRequest;
//------------------------------------------------------------------------------

 end else begin
  case(State)
   Idle:; // Wait for SETUP, which is the short-circuit state above
//------------------------------------------------------------------------------

   GetRequest: begin
    if(OUT_Valid) begin
     Request <= OUT_Data;
     State   <= GetValueLow;
    end
   end
//------------------------------------------------------------------------------

   GetValueLow: begin
    if(OUT_Valid) begin
     Value[7:0] <= OUT_Data;
     State      <= GetValueHigh;
    end
   end
//------------------------------------------------------------------------------

   GetValueHigh: begin
    if(OUT_Valid) begin
     Value[15:8] <= OUT_Data;
     State       <= GetIndexLow;
    end
   end
//------------------------------------------------------------------------------

   GetIndexLow: begin
    if(OUT_Valid) begin
     Index[7:0] <= OUT_Data;
     State      <= GetIndexHigh;
    end
   end
//------------------------------------------------------------------------------

   GetIndexHigh: begin
    if(OUT_Valid) begin
     Index[15:8] <= OUT_Data;
     State       <= GetLengthLow;
    end
   end
//------------------------------------------------------------------------------

   GetLengthLow: begin
    if(OUT_Valid) begin
     Length[7:0] <= OUT_Data;
     State       <= GetLengthHigh;
    end
   end
//------------------------------------------------------------------------------

   GetLengthHigh: begin
    if(OUT_Valid) begin
     Length[15:8] <= OUT_Data;
     State        <= GetEoP;
    end
   end
//------------------------------------------------------------------------------

   GetEoP: begin
    if(OUT_Valid & OUT_EoP) begin
     case({Type, Request})
      // Standard
//      {2'b00, GET_STATUS}:        State <= GetStatus;
//      {2'b00, CLEAR_FEATURE}:     State <= ClearFeature;
//      {2'b00, SET_FEATURE}:       State <= SetFeature;
      {2'b00, SET_ADDRESS}:       State <= SetAddress;
      {2'b00, GET_DESCRIPTOR}:    State <= GetDescriptor;
//      {2'b00, SET_DESCRIPTOR}:    State <= SetDescriptor;
//      {2'b00, GET_CONFIGURATION}: State <= GetConfiguration;
      {2'b00, SET_CONFIGURATION}: State <= SetConfiguration;
//      {2'b00, GET_INTERFACE}:     State <= GetInterface;
      {2'b00, SET_INTERFACE}:     State <= SetInterface;
//      {2'b00, SYNCH_FRAME}:       State <= SynchFrame;

      // Class Specific
      {2'b01, SET_CUR   }: State <= SetControl; // Set Current    (Audio)
      {2'b01, GET_CUR   },                      // Get Current    (Audio)
      {2'b01, GET_MIN   },                      // Get Minimum    (Audio)
      {2'b01, GET_MAX   },                      // Get Maximum    (Audio)
      {2'b01, GET_RES   },                      // Get Resolution (Audio)
      {2'b01, GET_REPORT}: State <= GetControl; // Get Report     (HID)

      // HID Class Specific

      default: begin
       Stall <= 1'b1;
       State <= Idle;
      end
     endcase
    end
   end
//------------------------------------------------------------------------------

   GetDescriptor: begin
    ByteCount <= 0;

    if(Error) begin
     Stall <= 1'b1;
     State <= Idle;
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

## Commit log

2016-08-20 Created project, assigned pins and set up SignalTap
    [USB_Reverse.stp]
2016-08-20 Implemented a crude receiver physical and made notes on how to improve it.
    The received bits are displayed in SignalTap.
    [USB_Reverse.stp]
2016-08-20 Crude extraction of Address and Endpoint fields
    This enables better triggerin in SignalTap.
    [USB_Reverse.stp]
2016-08-22 Implemented a much better receiver:
    - Handles the reset signalling correctly
    - Superior clock-recovery
    - Cleaner and easier-to-read code
    [USB_Reverse.stp]
2016-08-23 Started on the transaction-handling state machine
    - CRC checking is working for both CRC-5 and CRC-16.
    - The PID, frame counter, adrress and end-point indicators are
    extracted correctly.
    [USB_Reverse.stp]
2016-08-28 Set up the descriptors and partial default control endpoint state machine
    Problems:
    - After the device descriptor is sent, the host requests another IN,
    which is always NACK-ed, which is wrong.
    [Descriptors.xls, USB_Reverse.csv, USB_Reverse.stp]
2016-08-29 The Windows driver installs correctly, the volume control works and it streams data
    Todo:
    - Description strings
    - FIFO queue for the audio samples
    - Audio clock recovery
    - Playback
    [Descriptors.xls, USB_Reverse.stp]
2016-08-31 Clock-recovery PLL locks and audio streams to PWM...
    The clock is still jittery, and the PWM is low frequency and low
    resolution.
    [Descriptors.xls, USB_Reverse.stp]
2016-09-03 New clock recovery, volume control and noise-shaping working.
    New clock recovery (noise-shaped period based) implemented and working.
    Audio volume control and noise-shaping implemented and working.
    [Descriptors.xls, USB_Amplifier.csv, USB_Amplifier.stp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]
2016-09-05 Better volume control
    [Descriptors.xls]
2016-09-15 Added HID interface, but the discriptor is rejected by the host...
    [Descriptors.xls, USB_Amplifier.stp]
2016-09-15 New HID descriptor accepted, but class-specific control is still wrong:
    - Set Idle returns stall
    - Clear Feature returns stall
    - Get Descriptor does not return for HID, Report or Physical descriptors (stalls)
    - Get Report stalls
    [Descriptors.xls, USB_Amplifier.stp]
2016-09-25 Block-diagrams and preliminary remote schematic
    [Descriptors.xls, Remote.dsn]
2016-09-25 Preliminary front panel schematic
    [Front Panel.dsn]
2016-09-25 Preliminary main board schematic
    [Main Board.dsn, Remote.dsn]
2016-09-30 Revised remote schematic
    [Remote.dsn]
2016-10-01 Remote flashing-LED "hello world" project is working
2016-10-01 Remote sleep and interrupts are working
2016-10-01 Optimised for long battery-life on the remote
    [Remote.dsn]
2016-10-01 Remote Cleaner module working
    [Remote.dsn]
2016-10-01 FPGA-side receives the remote status correctly
    [global.h, main.c]
2016-10-01 Included the test PCB (and its schematic)
    [Tester.dsn]
2016-10-02 Fixed the clock-domain crossing between the buttons and HID
    The buttons are now less likely to stick.
    [Descriptors.xls]
2016-10-02 Laid out the remote PCB (4-layer version)
    [Remote.dsn]
2016-10-02 Fixed pin spacing on remote tactile switches
    [Remote.dsn]
2016-10-03 Designed a PCB version of the icon (InkScape)
2016-10-03 Updated remote PCB layout with newest info on the enclosure.
    [Main Board.dsn, Remote.dsn]
2016-10-03 Modified the remote to use 12 V on the RF Tx module
    - The PIC runs off 2x 1.5 V AAA batteries
    - The RF-Link runs of 1x 12 V A23 battery
    [Main Board.dsn, Remote.dsn]
2016-10-06 Added resistors to the remote programming pins in order to support a future "Address" feature
    [Remote.dsn]
2016-10-07 Moved the bus supply onto a separate board
    [Bus Supply.dsn, Main Board.dsn]
2016-10-07 Changed the bus supply's 12 V primary back to a Mornsun module
    The charge-pump's ripple-current is too high for the capacitor to handle.
    [Bus Supply.dsn]
2016-10-09 Cleaned up the Bus Supply schematic
    Also added a Primary_OK signal to tell the controller when the bus
    is ready.
    [Bus Supply.dsn]
2016-10-12 SketchUp model of the intended chassis
    [Chassis.skp]
2016-10-12 Added skrews to the chassis model
    [Amplifier.skp, Chassis.skp]
2016-10-13 Made the chassis skrews flush
    [Chassis.skp]
2016-10-13 Draw a TO-220
    [Amplifier.skp, Chassis.skp, TO-220.skp]
2016-10-13 Added capacitors and output inductors to SketchUp Model
    [Amplifier.skp, C_22mm.skp]
2016-10-14 Drew a skrew terminal
    [Amplifier.skp, Skrew Terminal.skp]
2016-10-17 Draw most of the remote control in SketchUp
    It fits in the box :-)
    [Remote.skp]
2016-10-17 Fixed the sketch of the 3mm LED
    [Remote.skp]
2016-10-17 Small refinements to the remote SketchUp drawing
    [Remote.skp]
2016-10-18 Added the RF-Link to the remote SketchUp model
    [Remote.skp]
2016-10-20 Cleaned up the remote SketchUp model
    - Fixed the RF-Link footprint
    - Ran solid inspector on all the components and fixed the errors
    [Remote.skp]
2016-10-21 More SketchUp housekeeping
    [Amplifier.skp, Chassis.skp, Skrew Terminal.skp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]
2016-10-24 Started on new amplifier 3D layout
    Also investigating a different remote layout...
    [Amplifier.skp, C_22mm.skp, Chassis.skp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]
2016-10-25 Preliminary large component placement in the amplifier 3D model
    [Amplifier.skp]
2016-10-26 Added most of the bulky components to the amplifier 3D model
    [Amplifier.skp, Bus Supply.dsn]
2018-07-21 Added links to the two Git repositories to the Wiki
    [Remote - Side Buttons.skp, Remote.skp]
2019-10-27 Changed the RF parts to reference by part number
    [Main Board.dsn, Remote.dsn]
2019-10-27 Updated the remote RF link to the new symbol and footprint
    [Remote.dsn]
2021-06-11 Converted the TinyCAD schematics to PDF

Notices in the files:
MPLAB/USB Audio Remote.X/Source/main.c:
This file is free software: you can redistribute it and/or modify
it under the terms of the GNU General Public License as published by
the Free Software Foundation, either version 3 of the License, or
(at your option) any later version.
